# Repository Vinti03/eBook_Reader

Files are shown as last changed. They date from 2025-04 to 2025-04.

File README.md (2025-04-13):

# OpenBook E-Book Reader
Made by: Vintilescu Andrei-Florin, 332CA

University: UNSTPB, Bucharest

## Conținutul Repository-ului

OpenBook

    Hardware

        OpenBook.sch            // Fișierul schematic

        OpenBook.brd            // Fișierul PCB

    Manufacturing

        gerbers.zip             // Pachetul Gerber generat

        OpenBook.bom            // Bill Of Materials (BOM)

        OpenBook.cpl            // Fișier Pick and Place

    Mechanical

        OpenBook_exploded.step  // Model 3D exploded view (PCB + baterie + display + carcasă)

        OpenBook_Fusion360.f3d  // Fișierul 3D nativ Fusion360

    Images

        pcb_render.png          // Imagine cu randări ale PCB-ului

        device_render.png       // Randări ale dispozitivului complet

    LICENSE                     // Licența open source (ex. Apache 2.0)

    README.md                   // Acest fișier

## Diagramă Bloc a Sistemului
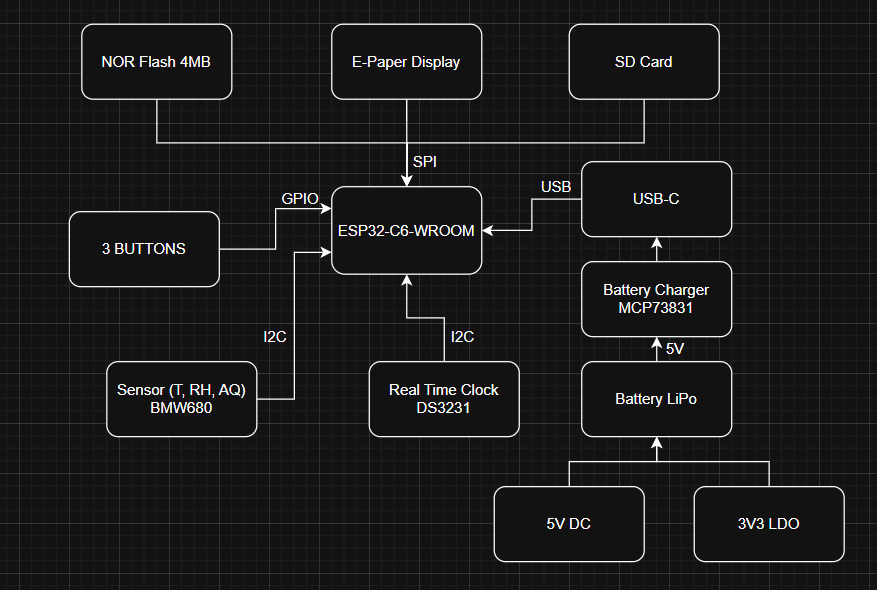
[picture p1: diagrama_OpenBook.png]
Diagrama bloc a proiectului OpenBook


## Bill Of Materials (BOM)

| Device | DATASHEET | PURCHASE-URL |
|---|---|---|
| ADAFRUIT_LEDCHIP-LED0603 | https://www.snapeda.com/parts/KP-1608SURCK/Kingbright/datasheet/ | https://www.snapeda.com/parts/KP-1608SURCK/Kingbright/view-part/?ref=search&t=LED%200603 |
| ESP32_WROVER_EAGLE-LTSPICE_RR0402 | https://analytics.supplyframe.com/trackingservlet/track/?r=0x34... (link lung) | https://componentsearchengine.com/part-view/R0402%201%25%20100%20K%20(RC0402FR-07100KL)/YAGEO |
| SJ | https://grabcad.com/library/solder-jumpers-1 | https://grabcad.com/library/solder-jumpers-1 |
| EAGLE-LTSPICE_CC0402 | https://analytics.supplyframe.com/trackingservlet/track/?r=0x34... (link lung) | https://componentsearchengine.com/part-view/CC0402MRX5R5BB106/YAGEO |
| ESP32_WROVER_EAGLE-LTSPICE_RR0402 | https://analytics.supplyframe.com/trackingservlet/track/?r=0x34... (link lung) | https://componentsearchengine.com/part-view/R0402%201%25%20100%20K%20(RC0402FR-07100KL)/YAGEO |
| ESP32_WROVER_EAGLE-LTSPICE_RR0402 | https://analytics.supplyframe.com/trackingservlet/track/?r=0x34... (link lung) | https://componentsearchengine.com/part-view/R0402%201%25%20100%20K%20(RC0402FR-07100KL)/YAGEO |
| EAGLE-LTSPICE_CC0402 | https://analytics.supplyframe.com/trackingservlet/track/?r=0x34... (link lung) | https://componentsearchengine.com/part-view/CC0402MRX5R5BB106/YAGEO |
| RCL_CPOL-EUCT3528 | https://s3.amazonaws.com/snapeda/datasheet/TAJB475K025RNJ_AVX.pdf | https://www.snapeda.com/parts/TAJB475K025RNJ/AVX/view-part/?ref=dk&t=capacitor%203528&con_ref=None |
| ESP32_WROVER_EAGLE-LTSPICE_RR0402 | https://analytics.supplyframe.com/trackingservlet/track/?r=0x34... (link lung) | https://componentsearchengine.com/part-view/R0402%201%25%20100%20K%20(RC0402FR-07100KL)/YAGEO |
| ESP32_WROVER_EAGLE-LTSPICE_RR0402 | https://analytics.supplyframe.com/trackingservlet/track/?r=0x34... (link lung) | https://componentsearchengine.com/part-view/R0402%201%25%20100%20K%20(RC0402FR-07100KL)/YAGEO |
| EAGLE-LTSPICE_CC0402 | https://analytics.supplyframe.com/trackingservlet/track/?r=0x34... (link lung) | https://componentsearchengine.com/part-view/CC0402MRX5R5BB106/YAGEO |
| 112A-TAAR-R03_ATTEND | https://store.comet.srl.ro/Catalogue/Product/43497/ | https://store.comet.srl.ro/Catalogue/Product/43497/ |
| ESP32_WROVER_EAGLE-LTSPICE_RR0402 | https://analytics.supplyframe.com/trackingservlet/track/?r=0x34... (link lung) | https://componentsearchengine.com/part-view/R0402%201%25%20100%20K%20(RC0402FR-07100KL)/YAGEO |
| EAGLE-LTSPICE_CC0402 | https://analytics.supplyframe.com/trackingservlet/track/?r=0x34... (link lung) | https://componentsearchengine.com/part-view/CC0402MRX5R5BB106/YAGEO |
| EAGLE-LTSPICE_CC0402 | https://analytics.supplyframe.com/trackingservlet/track/?r=0x34... (link lung) | https://componentsearchengine.com/part-view/CC0402MRX5R5BB106/YAGEO |
| ESP32_WROVER_EAGLE-LTSPICE_RR0402 | https://analytics.supplyframe.com/trackingservlet/track/?r=0x34... (link lung) | https://componentsearchengine.com/part-view/R0402%201%25%20100%20K%20(RC0402FR-07100KL)/YAGEO |
| ESP32_WROVER_EAGLE-LTSPICE_RR0402 | https://analytics.supplyframe.com/trackingservlet/track/?r=0x34... (link lung) | https://componentsearchengine.com/part-view/R0402%201%25%20100%20K%20(RC0402FR-07100KL)/YAGEO |
| ESP32_WROVER_SPARKFUN-DISCRETESEMI_MOSFET_PCH-DMG2305UX-7 | https://analytics.supplyframe.com/trackingservlet/track/?r=0x34... (link lung) | https://componentsearchengine.com/part-view/DMG2305UX-7/Diodes%20Incorporated |
| ESP32_WROVER_EAGLE-LTSPICE_RR0402 | https://analytics.supplyframe.com/trackingservlet/track/?r=0x34... (link lung) | https://componentsearchengine.com/part-view/R0402%201%25%20100%20K%20(RC0402FR-07100KL)/YAGEO |
| EAGLE-LTSPICE_CC0402 | https://analytics.supplyframe.com/trackingservlet/track/?r=0x34... (link lung) | https://componentsearchengine.com/part-view/CC0402MRX5R5BB106/YAGEO |
| EAGLE-LTSPICE_CC0402 | https://analytics.supplyframe.com/trackingservlet/track/?r=0x34... (link lung) | https://componentsearchengine.com/part-view/CC0402MRX5R5BB106/YAGEO |
| ESP32_WROVER_EAGLE-LTSPICE_RR0402 | https://analytics.supplyframe.com/trackingservlet/track/?r=0x34... (link lung) | https://componentsearchengine.com/part-view/R0402%201%25%20100%20K%20(RC0402FR-07100KL)/YAGEO |
| 744043680IND_4828-WE-TPC_WRE | https://www.we-online.com/components/products/datasheet/744043680.pdf | https://eu.mouser.com/ProductDetail/Wurth-Elektronik/744043680?qs=PGXP4M47uW6VkZq%252BkzjrHA%3D%3D |
| BD5229G-TR | https://analytics.supplyframe.com/trackingservlet/track/?r=0x34... (link lung) | https://componentsearchengine.com/part-view/XC6220A331MR-G/Torex |
| ESP32_WROVER_BME680_BME680 | https://www.snapeda.com/parts/BME680/Bosch%20Sensortec/datasheet/ | https://www.google.com/url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... |
| BUTTON_CUSYOMV1 | https://industry.panasonic.com/global/en/downloads?tab=catalog&small_g_cd=203&part_no=EVQPUJ02K | https://industry.panasonic.com/global/en/products/control/switch/light-touch/number/evqpuj02k |
| CPH3225A | https://www.snapeda.com/parts/CPH3225A/Seiko%20Instruments/datasheet/ | https://www.snapeda.com/parts/CPH3225A/Seiko+Instruments/view-part/?ref=eda |
| DS3231SN# | https://www.snapeda.com/parts/DS3231SN%23/Analog%20Devices/datasheet/ | https://www.snapeda.com/parts/DS3231SN%23/Analog+Devices/view-part/?ref=eda |
| ESP32-C6-WROOM-1-N8 | https://www.snapeda.com/parts/ESP32-C6-WROOM-1-N8/Espressif%20Systems/datasheet/ | https://www.snapeda.com/parts/ESP32-C6-WROOM-1-N8/Espressif+Systems/view-part/?ref=eda |
| ESP32C6_VARISTORCN1812 | https://www.snapeda.com/parts/MOV-10D561K/Bourns/datasheet/ | https://www.snapeda.com/parts/MOV-10D561K/Bourns/view-part/?welcome=home&ref=search&t=varistor |
| ESP32_WROVER_AVX---SD0805S020S1R0_AVX_SD0805S020S1R0_0_0AVX_SD0805S020S1R0_0_0 | https://ro.mouser.com/datasheet/2/40/schottky-3165252.pdf | https://ro.mouser.com/ProductDetail/KYOCERA-AVX/SD0805S020S1R0?qs=jCA%252BPfw4LHbpkAoSnwrdjw%3D%3D |
| ESP32_WROVER_SPARKFUN-IC-POWER_MCP73831 | https://eu.mouser.com/datasheet/2/268/MCP73831_Family_Data_Sheet_DS20001984H-3441711.pdf | https://eu.mouser.com/ProductDetail/Microchip-Technology/MCP73831T-2ACI-OT?qs=yUQqVecv4qvbBQBGbHx0Mw%3D%3D |
| FH34SRJ-24S-0.5SH_99_ | https://analytics.supplyframe.com/trackingservlet/track/?r=0x34... (link lung) | https://componentsearchengine.com/part-view/FH34SRJ-24S-0.5SH(99)/Hirose |
| MAX17048G+T10 | https://www.snapeda.com/parts/MAX17048G+T10/Analog%20Devices/datasheet/ | https://www.snapeda.com/parts/MAX17048G+T10/Analog+Devices/view-part/?ref=eda |
| MBR0530 | https://www.snapeda.com/parts/MBR0530/ON%20Semiconductor/datasheet/ | https://www.snapeda.com/parts/MBR0530/Onsemi/view-part/?ref=eda |
| PGB1010603MR | https://www.snapeda.com/parts/PGB1010603MR/Littelfuse%20Inc./datasheet/ | https://www.snapeda.com/parts/PGB1010603MR/Littelfuse/view-part/?ref=eda |
| QWIIC_RIGHT_ANGLE | https://eu.mouser.com/ProductDetail/Adafruit/4208?qs=PzGy0jfpSMtbScLbr0L5dw%3D%3D | https://eu.mouser.com/ProductDetail/Adafruit/4208?qs=PzGy0jfpSMtbScLbr0L5dw%3D%3D |
| SAMACSYS_PARTS_USB4110-GF-A | https://analytics.supplyframe.com/trackingservlet/track/?r=0x34... (link lung) | https://componentsearchengine.com/part-view/USB4110-GF-A/GCT%20(GLOBAL%20CONNECTOR%20TECHNOLOGY) |
| ESP32_WROVER_AVX---SD0805S020S1R0_AVX_SD0805S020S1R0_0_0AVX_SD0805S020S1R0_0_0 | https://ro.mouser.com/datasheet/2/40/schottky-3165252.pdf | https://ro.mouser.com/ProductDetail/KYOCERA-AVX/SD0805S020S1R0?qs=jCA%252BPfw4LHbpkAoSnwrdjw%3D%3D |
| SI1308EDL-T1-GE3 | https://www.snapeda.com/parts/SI1308EDL-T1-GE3/Vishay%20Siliconix/datasheet/ | https://www.snapeda.com/parts/SI1308EDL-T1-GE3/Vishay+Siliconix/view-part/?ref=eda |
| TPTP20R | self made | self made |
| USBLC6-2SC6Y | https://www.snapeda.com/parts/USBLC6-2SC6Y/STMicroelectronics/datasheet/ | https://www.snapeda.com/parts/USBLC6-2SC6Y/STMicroelectronics/view-part/?ref=eda |
| W25Q512JVEIQ | https://www.snapeda.com/parts/W25Q512JVEIQ/Winbond%20Electronics/datasheet/ | https://www.snapeda.com/parts/W25Q512JVEIQ/Winbond+Electronics/view-part/?ref=eda |
| XC6220A331MR-G | https://analytics.supplyframe.com/trackingservlet/track/?r=0x34... (link lung) | |

*Notă:* De asemenea lista completa de componente cu linkurile complete pentru datasheet si purchase-url o gasiti consultand fișierul `BOM.csv` inclus în directorul Manufacturing.

---

## Funcționalitatea Hardware în Detaliu

Acest proiect integrează următoarele module și componente:

- **ESP32-C6 Microcontroller:**  
  - Rol: Procesare centrală și interfațare cu toate componentele.  
  - Interfețe:  
    - UART pentru comunicare cu modulul e-Paper  
    - SPI pentru senzorii periferici  
    - I2C pentru conectarea accelerometrului și a altor senzori  
  - Specificații: Calcul estimativ de consum energetic, rutare optimizată a pinilor și implementare a planurilor de masă pe ambele straturi (TOP și BOTTOM) pentru stabilitate electrică.

- **Display e-Paper:**  
  - Rol: Afișare de text și imagini cu consum redus de energie.  
  - Interfață: SPI, cu un set dedicat de pini conectați direct la ESP32-C6.
  
- **Baterie LiPo:**  
  - Rol: Alimentarea dispozitivului.  
  - Observații: Bateria este conectată direct la patru test pad-uri conform specificațiilor pentru economisirea spațiului.  
 
- **Decuplaje și Protecții:**  
  - Utilizare condensatoare 100 nF amplasate cât mai aproape de pinii de alimentare pentru a asigura o decuplare corespunzătoare.  
  - Rutare a traseelor de putere la 0.3mm, iar semnalele de date la cel puțin 0.15mm conform specificațiilor.

- **Plan de Masă și Rutare:**  
  - Implementare a unui plan de masă atât pe layer-ul TOP cât și pe BOTTOM.  
  - Vias-urile au fost plasate strategic și folosim tehnici de Via Stitching, în special în zona modulului ESP32, pentru a minimiza interferențele.

- **Constrângeri Mecanice:**  
  - PCB-ul de 1mm grosime este proiectat să se încadreze perfect în carcasa specificată.  
  - Toate componentele principale sunt grupate în jurul microcontroller-ului și amplasate exclusiv pe layer-ul TOP de conformitate cu cerințele proiectului.

---

## Configurarea și Utilizarea Pinii ESP32-C6

Mai jos este un sumar al pinilor utilizați și a motivelor alese:

| Pin ESP32-C6 | Funcționalitate Asociată | Motiv/Observații |
|---|---|---|
| GPIO12 | SPI_MISO pentru Display e-Paper  | Necesită viteză mare și stabilitate la semnal  |
| GPIO13 | SPI_MOSI pentru Display e-Paper  | Pentru comunicații rapide și fiabile |
| GPIO14 | SPI_CLK pentru Display e-Paper | Sincronizare precisă a semnalului |
| GPIO15 | CS (Chip Select) pentru e-Paper  | Control dedicated pentru selecție modul |
| GPIO2 | I2C SDA pentru Senzori | Interfață I2C standard pentru accelerometru/senzori |
| GPIO4 | I2C SCL pentru Senzori | Necesită semnal clar pentru sincronizarea I2C  |
| ... | Alte pini alocați conform necesităților proiectului | Consultare schema detaliată pentru alocare |

## Concluzie

  Proiectul OpenBook a urmarit dezvoltarea unui dispozitiv e-book reader accesibil, open-source, cu un design hardware optimizat pentru productie de masa. Am parcurs toate etapele de validare, de la schema electrica si PCB pana la integrarea mecanica completa in carcasa finala. Design-ul respecta constrangerile functionale, mecanice si de buna practica, fiind pregatit pentru testare si productie. Documentatia completa si fisierele necesare sunt disponibile in acest repository.

---

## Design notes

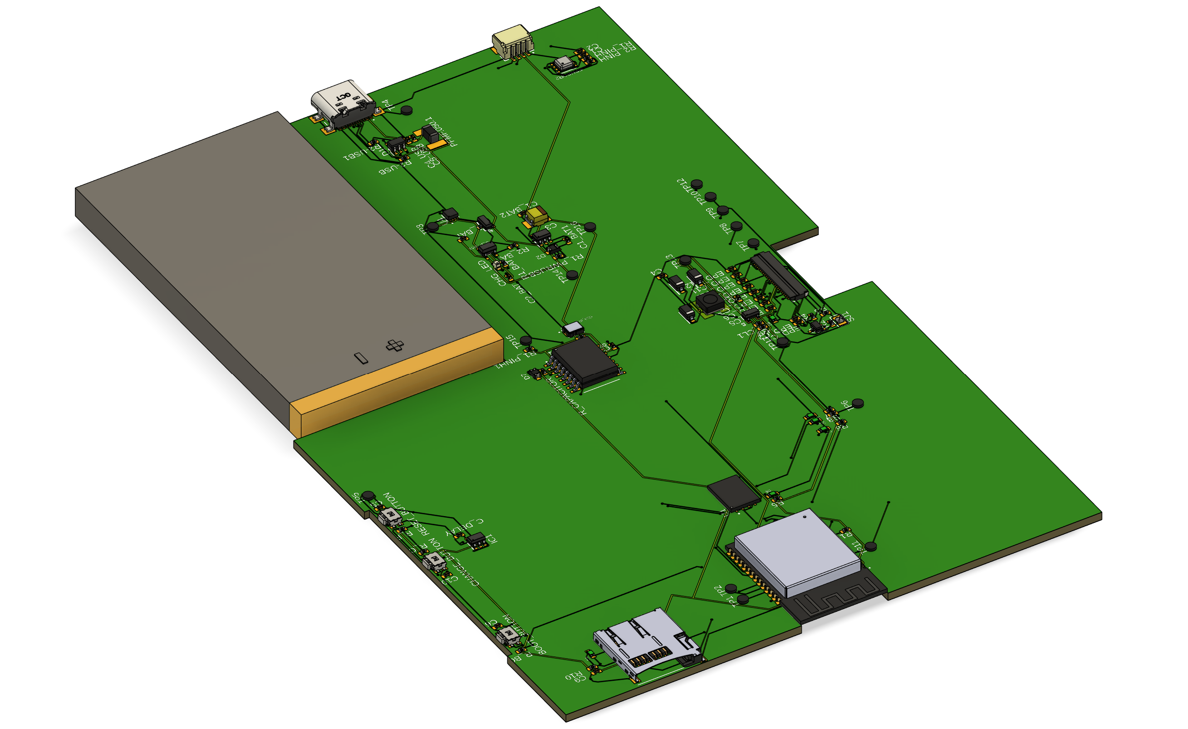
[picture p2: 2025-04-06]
Images/PCDB with Battery.png

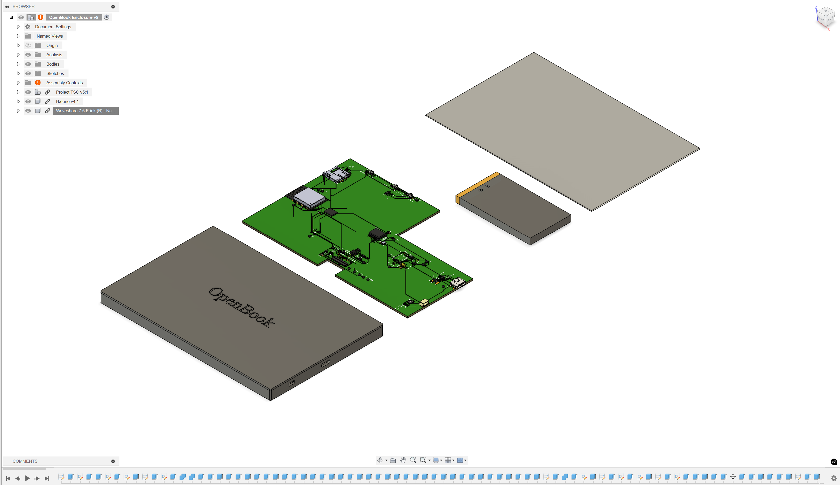
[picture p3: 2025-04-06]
Images/Exploded view.png

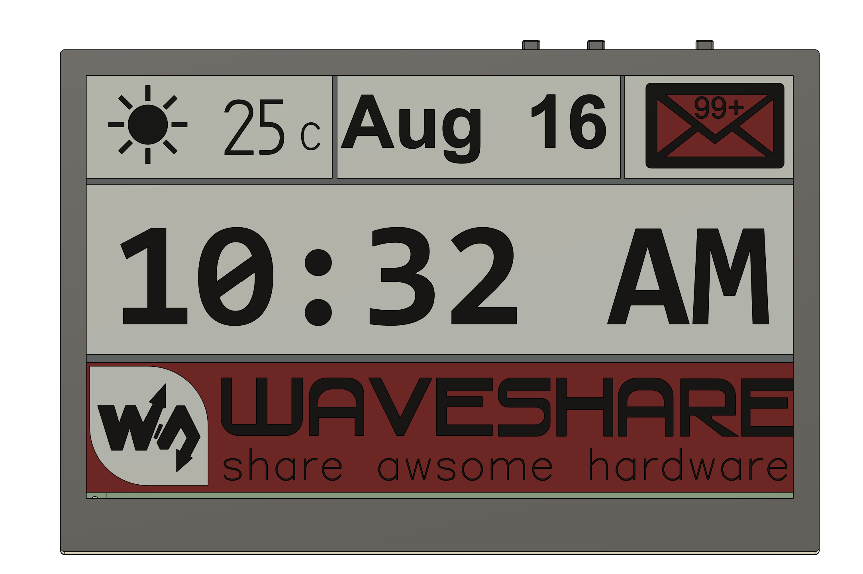
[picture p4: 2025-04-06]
Images/The final product.png

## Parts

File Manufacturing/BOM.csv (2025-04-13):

Qty | Value | Device | Package | Parts | Description | ARROW_PART_NUMBER | ARROW_PRICE-STOCK | AVAILABILITY | CENTROID_NOT_SPECIFIED | CHECK_PRICES | COPYRIGHT | DATASHEET | DESCRIPTION | DIGIKEY_DESCRIPTION | DIGIKEY_PART_NUMBER | HEIGHT | LEAD_FREE | MANUFACTURER_NAME | MANUFACTURER_PART_NUMBER | MF | MFR_NAME | MOUSER_PART_NUMBER | MOUSER_PRICE-STOCK | MOUSER_TESTING_PART_NUMBER | MOUSER_TESTING_PRICE-STOCK | MP | MPN | PACKAGE | POPULARITY | PREFIX | PRICE | PROD_ID | PURCHASE-URL | ROHS | SNAPEDA_LINK | SPICEMODEL | SPICEPREFIX | TEMPERATURE_RANGE_HIGH | TEMPERATURE_RANGE_LOW | TP_SIGNAL_NAME | VALUE
1 |  | ADAFRUIT_LEDCHIP-LED0603 | ADAFRUIT_CHIP-LED0603 | CHG_LED | LED |  |  |  |  |  | https://www.snapeda.com/parts/KP-1608SURCK/Kingbright/datasheet/ | https://www.snapeda.com/parts/KP-1608SURCK/Kingbright/datasheet/ |  |  |  |  |  |  |  |  |  |  |  |  |  |  |  |  |  |  |  |  | https://www.snapeda.com/parts/KP-1608SURCK/Kingbright/view-part/?ref=search&t=LED%200603
2 |  | ESP32_WROVER_EAGLE-LTSPICE_RR0402 | ESP32_WROVER_EAGLE-LTSPICE_R0402 | R1, R_CHANGE | RESISTOR, European symbol |  |  |  |  |  |  | https://analytics.supplyframe.com/trackingservlet/track/ |  |  |  |  |  |  |  |  |  |  |  |  |  |  |  |  |  |  |  |  | https://componentsearchengine.com/part-view/R0402%201%25%20100%20K%20(RC0402FR-07100KL)/YAGEO |  |  | NONE | R
1 |  | SJ | SJ | SJ1 | SMD solder JUMPER |  |  |  |  |  |  | https://grabcad.com/library/solder-jumpers-1 |  |  |  |  |  |  |  |  |  |  |  |  |  |  |  |  | 3 |  |  |  | https://grabcad.com/library/solder-jumpers-1
1 | 0.1uF/50V | EAGLE-LTSPICE_CC0402 | EAGLE-LTSPICE_C0402 | EPD_C5 | CAPACITOR, European symbol |  |  |  |  |  |  | https://analytics.supplyframe.com/trackingservlet/track/ |  |  |  |  |  |  |  |  |  |  |  |  |  |  |  |  |  |  |  |  | https://componentsearchengine.com/part-view/CC0402MRX5R5BB106/YAGEO |  |  | NONE | C
1 | 0.47 | ESP32_WROVER_EAGLE-LTSPICE_RR0402 | ESP32_WROVER_EAGLE-LTSPICE_R0402 | R3 | RESISTOR, European symbol |  |  |  |  |  |  | https://analytics.supplyframe.com/trackingservlet/track/ |  |  |  |  |  |  |  |  |  |  |  |  |  |  |  |  |  |  |  |  | https://componentsearchengine.com/part-view/R0402%201%25%20100%20K%20(RC0402FR-07100KL)/YAGEO |  |  | NONE | R
1 | 100k | ESP32_WROVER_EAGLE-LTSPICE_RR0402 | ESP32_WROVER_EAGLE-LTSPICE_R0402 | R1_PWRUSB | RESISTOR, European symbol |  |  |  |  |  |  | https://analytics.supplyframe.com/trackingservlet/track/ |  |  |  |  |  |  |  |  |  |  |  |  |  |  |  |  |  |  |  |  | https://componentsearchengine.com/part-view/R0402%201%25%20100%20K%20(RC0402FR-07100KL)/YAGEO |  |  | NONE | R
8 | 100nF | EAGLE-LTSPICE_CC0402 | EAGLE-LTSPICE_C0402 | C1, C2, C4_USB, C6, C8, C9, C10, C_DELAY | CAPACITOR, European symbol |  |  |  |  |  |  | https://analytics.supplyframe.com/trackingservlet/track/ |  |  |  |  |  |  |  |  |  |  |  |  |  |  |  |  |  |  |  |  | https://componentsearchengine.com/part-view/CC0402MRX5R5BB106/YAGEO |  |  | NONE | C
1 | 100uF TANT | RCL_CPOL-EUCT3528 | RCL_CT3528 | C3 | POLARIZED CAPACITOR, European symbol |  |  |  |  |  |  | https://s3.amazonaws.com/snapeda/datasheet/TAJB475K025RNJ_AVX.pdf |  |  |  |  |  |  |  |  |  |  |  |  |  |  |  |  | 0 |  |  |  | https://www.snapeda.com/parts/TAJB475K025RNJ/AVX/view-part/?ref=dk&t=capacitor%203528&con_ref=None |  |  |  | C
13 | 10K | ESP32_WROVER_EAGLE-LTSPICE_RR0402 | ESP32_WROVER_EAGLE-LTSPICE_R0402 | R1_PINH, R1_PINH1, R2-PINH1, R2_PINH, R5, R6, R7, R8, R9, R10, R_BOOT, R_CL1, R_RESET | RESISTOR, European symbol |  |  |  |  |  |  | https://analytics.supplyframe.com/trackingservlet/track/ |  |  |  |  |  |  |  |  |  |  |  |  |  |  |  |  |  |  |  |  | https://componentsearchengine.com/part-view/R0402%201%25%20100%20K%20(RC0402FR-07100KL)/YAGEO |  |  | NONE | R
1 | 10k | ESP32_WROVER_EAGLE-LTSPICE_RR0402 | ESP32_WROVER_EAGLE-LTSPICE_R0402 | R4 | RESISTOR, European symbol |  |  |  |  |  |  | https://analytics.supplyframe.com/trackingservlet/track/ |  |  |  |  |  |  |  |  |  |  |  |  |  |  |  |  |  |  |  |  | https://componentsearchengine.com/part-view/R0402%201%25%20100%20K%20(RC0402FR-07100KL)/YAGEO |  |  | NONE | R
1 | 10uF | EAGLE-LTSPICE_CC0402 | EAGLE-LTSPICE_C0402 | C7 | CAPACITOR, European symbol |  |  |  |  |  |  | https://analytics.supplyframe.com/trackingservlet/track/ |  |  |  |  |  |  |  |  |  |  |  |  |  |  |  |  |  |  |  |  | https://componentsearchengine.com/part-view/CC0402MRX5R5BB106/YAGEO |  |  | NONE | C
1 | 112A-TAAR-R03_ATTEND | 112A-TAAR-R03_ATTEND | 112ATAARR03ATTEND | J4 | Micro SD Card Socket, Push-Push Type, Top Mount, SMT, H=1.83mm, 10u |  |  |  |  |  |  | https://store.comet.srl.ro/Catalogue/Product/43497/ | Micro SD Card Socket | Push-Push Type | Top Mount | SMT | H=1.83mm | 10u |  |  | 1.9mm |  | ATTEND | 112A-TAAR-R03 ATTEND |  |  |  |  |  |  |  |  | https://store.comet.srl.ro/Catalogue/Product/43497/
1 | 15 | ESP32_WROVER_EAGLE-LTSPICE_RR0402 | ESP32_WROVER_EAGLE-LTSPICE_R0402 | R_CAPACITOR | RESISTOR, European symbol |  |  |  |  |  |  | https://analytics.supplyframe.com/trackingservlet/track/ |  |  |  |  |  |  |  |  |  |  |  |  |  |  |  |  |  |  |  |  | https://componentsearchengine.com/part-view/R0402%201%25%20100%20K%20(RC0402FR-07100KL)/YAGEO |  |  | NONE | R
1 | 1uF | EAGLE-LTSPICE_CC0402 | EAGLE-LTSPICE_C0402 | C5 | CAPACITOR, European symbol |  |  |  |  |  |  | https://analytics.supplyframe.com/trackingservlet/track/ |  |  |  |  |  |  |  |  |  |  |  |  |  |  |  |  |  |  |  |  | https://componentsearchengine.com/part-view/CC0402MRX5R5BB106/YAGEO |  |  | NONE | C
9 | 1uF/50V | EAGLE-LTSPICE_CC0402 | EAGLE-LTSPICE_C0402 | EPD_C1, EPD_C2, EPD_C6, EPD_C7, EPD_C8, EPD_C9, EPD_C10, EPD_C11, EPD_C12 | CAPACITOR, European symbol |  |  |  |  |  |  | https://analytics.supplyframe.com/trackingservlet/track/ |  |  |  |  |  |  |  |  |  |  |  |  |  |  |  |  |  |  |  |  | https://componentsearchengine.com/part-view/CC0402MRX5R5BB106/YAGEO |  |  | NONE | C
1 | 2.2 | ESP32_WROVER_EAGLE-LTSPICE_RR0402 | ESP32_WROVER_EAGLE-LTSPICE_R0402 | R2 | RESISTOR, European symbol |  |  |  |  |  |  | https://analytics.supplyframe.com/trackingservlet/track/ |  |  |  |  |  |  |  |  |  |  |  |  |  |  |  |  |  |  |  |  | https://componentsearchengine.com/part-view/R0402%201%25%20100%20K%20(RC0402FR-07100KL)/YAGEO |  |  | NONE | R
1 | 200 | ESP32_WROVER_EAGLE-LTSPICE_RR0402 | ESP32_WROVER_EAGLE-LTSPICE_R0402 | R1_BAT | RESISTOR, European symbol |  |  |  |  |  |  | https://analytics.supplyframe.com/trackingservlet/track/ |  |  |  |  |  |  |  |  |  |  |  |  |  |  |  |  |  |  |  |  | https://componentsearchengine.com/part-view/R0402%201%25%20100%20K%20(RC0402FR-07100KL)/YAGEO |  |  | NONE | R
2 | 20V/4.2A/52mO/1.4W | ESP32_WROVER_SPARKFUN-DISCRETESEMI_MOSFET_PCH-DMG2305UX-7 | ESP32_WROVER_SPARKFUN-DISCRETESEMI_SOT23-3 | Q1, Q2 | P-channel MOSFETs |  |  |  |  |  |  | https://analytics.supplyframe.com/trackingservlet/track/ |  |  |  |  |  |  |  |  |  |  |  |  |  |  |  |  |  |  |  | TRAN-14388 | https://componentsearchengine.com/part-view/DMG2305UX-7/Diodes%20Incorporated |  |  |  |  |  |  |  | 20V/4.2A/52mO/1.4W
1 | 2K | ESP32_WROVER_EAGLE-LTSPICE_RR0402 | ESP32_WROVER_EAGLE-LTSPICE_R0402 | R2_BAT | RESISTOR, European symbol |  |  |  |  |  |  | https://analytics.supplyframe.com/trackingservlet/track/ |  |  |  |  |  |  |  |  |  |  |  |  |  |  |  |  |  |  |  |  | https://componentsearchengine.com/part-view/R0402%201%25%20100%20K%20(RC0402FR-07100KL)/YAGEO |  |  | NONE | R
5 | 4.7uF | EAGLE-LTSPICE_CC0402 | EAGLE-LTSPICE_C0402 | C1_BAT, C1_BAT1, C1_BAT2, C2_BAT, C5_USB | CAPACITOR, European symbol |  |  |  |  |  |  | https://analytics.supplyframe.com/trackingservlet/track/ |  |  |  |  |  |  |  |  |  |  |  |  |  |  |  |  |  |  |  |  | https://componentsearchengine.com/part-view/CC0402MRX5R5BB106/YAGEO |  |  | NONE | C
1 | 4.7uF/25V | EAGLE-LTSPICE_CC0402 | EAGLE-LTSPICE_C0402 | C4 | CAPACITOR, European symbol |  |  |  |  |  |  | https://analytics.supplyframe.com/trackingservlet/track/ |  |  |  |  |  |  |  |  |  |  |  |  |  |  |  |  |  |  |  |  | https://componentsearchengine.com/part-view/CC0402MRX5R5BB106/YAGEO |  |  | NONE | C
2 | 5k1 | ESP32_WROVER_EAGLE-LTSPICE_RR0402 | ESP32_WROVER_EAGLE-LTSPICE_R0402 | R2-USB, R2-USB1 | RESISTOR, European symbol |  |  |  |  |  |  | https://analytics.supplyframe.com/trackingservlet/track/ |  |  |  |  |  |  |  |  |  |  |  |  |  |  |  |  |  |  |  |  | https://componentsearchengine.com/part-view/R0402%201%25%20100%20K%20(RC0402FR-07100KL)/YAGEO |  |  | NONE | R
1 | 68uH | 744043680IND_4828-WE-TPC_WRE | IND_4828-WE-TPC_WRE | L1 |  |  |  |  |  |  | Copyright (C) 2024 Ultra Librarian. All rights reserved. | https://www.we-online.com/components/products/datasheet/744043680.pdf |  |  |  |  |  |  | 744043680 |  | Wurth Electronics |  |  |  |  |  |  |  |  |  |  |  | https://eu.mouser.com/ProductDetail/Wurth-Elektronik/744043680?qs=PGXP4M47uW6VkZq%252BkzjrHA%3D%3D
1 | BD5229G-TR | BD5229G-TR | SOT95P280X120-5N | IC1 | Voltage Detector with Adjustable Delay Time: CMOS processes are utilized to develop high precision, low current consumption CMOS reset ICs that allow arbitrary setting of the delay time. The extensive lineup includes both Nch Open Drain and CMOS output types in a wide range of detection voltages (from 2.3V to 6.0V, in 0.1V steps), enabling selection of the ideal solution based on customer requirements. In addition, the entire series is of course both lead-free and RoHS-compliant. |  |  |  |  |  |  | https://analytics.supplyframe.com/trackingservlet/track/ | Voltage Detector with Adjustable Delay Time: CMOS processes are utilized to develop high precision | low current consumption CMOS reset ICs that allow arbitrary setting of the delay time. The extensive lineup includes both Nch Open Drain and CMOS output types in a wide range of detection voltages (from 2.3V to 6.0V | in 0.1V steps) | enabling selection of the ideal solution based on customer requirements. In addition | the entire series is of course both lead-free and RoHS-compliant. |  |  | 1.25mm |  | ROHM Semiconductor | BD5229G-TR |  |  | 755-BD5229G-TR | https://www.mouser.co.uk/ProductDetail/ROHM-Semiconductor/BD5229G-TR?qs=4kLU8WoGk0vvnhrrYwdszw%3D%3D |  |  |  |  |  | https://componentsearchengine.com/part-view/XC6220A331MR-G/Torex
1 | BME688 | ESP32_WROVER_BME680_BME680 | ESP32_WROVER_BME680_PSON80P300X300X100-8N | SENSOR2 | Integrated Environmental Unit |  |  | Unavailable |  |  |  | https://www.snapeda.com/parts/BME680/Bosch%20Sensortec/datasheet/ | Integrated Environmental Unit |  |  |  |  |  |  | Bosch Sensortec |  |  |  |  |  | BME680 |  | LGA-8 Bosch Tools |  |  | None |  | https://www.snapeda.com/parts/BME680/Bosch/view-part/?welcome=home
3 | BUTTON_CUSYOMV1 | BUTTON_CUSYOMV1 | MYBUTTON | BOOT_BUTTON, CHANGE_BUTTON, RESET_BUTTON |  |  |  |  |  |  |  | https://industry.panasonic.com/global/en/downloads?tab=catalog&small_g_cd=203&part_no=EVQPUJ02K |  |  |  |  |  |  |  |  |  |  |  |  |  |  |  |  |  |  |  |  | https://industry.panasonic.com/global/en/products/control/switch/light-touch/number/evqpuj02k
1 | CPH3225A | CPH3225A | CAPCP3225X100N | C10_SUPERCAP | Cap 0.011F 3.3V 1210 Flat Check availability |  |  | Not in stock |  | https://www.snapeda.com/parts/CPH3225A/Seiko+Instruments/view-part/?ref=eda |  | https://www.snapeda.com/parts/CPH3225A/Seiko%20Instruments/datasheet/ | 11 mF (EDLC) Supercapacitor 3.3 V 1210 (3225 Metric) - - |  |  |  |  |  |  | Seiko Instruments |  |  |  |  |  | CPH3225A |  | 1210 Seiko |  |  | None |  | https://www.snapeda.com/parts/CPH3225A/Seiko+Instruments/view-part/?ref=eda |  | https://www.snapeda.com/parts/CPH3225A/Seiko+Instruments/view-part/?ref=snap
1 | DS3231SN# | DS3231SN# | SOIC127P1032X265-16N | U3 | Real Time Clock Serial 16-Pin SOIC W T/R Check availability |  |  | In Stock |  | https://www.snapeda.com/parts/DS3231SN%23/Analog+Devices/view-part/?ref=eda |  | https://www.snapeda.com/parts/DS3231SN%23/Analog%20Devices/datasheet/ | Extremely Accurate I涎-Integrated RTC/TCXO/Crystal |  |  |  |  |  |  | Analog Devices |  |  |  |  |  | DS3231SN# |  | SOIC-16 Maxim |  |  | None |  | https://www.snapeda.com/parts/DS3231SN%23/Analog+Devices/view-part/?ref=eda |  | https://www.snapeda.com/parts/DS3231SN%23/Analog+Devices/view-part/?ref=snap
1 | ESP32-C6-WROOM-1-N8 | ESP32-C6-WROOM-1-N8 | XCVR_ESP32-C6-WROOM-1-N8 | U2 | Check availability |  |  | In Stock |  | https://www.snapeda.com/parts/ESP32-C6-WROOM-1-N8/Espressif+Systems/view-part/?ref=eda |  | https://www.snapeda.com/parts/ESP32-C6-WROOM-1-N8/Espressif%20Systems/datasheet/ | Multiprotocol Modules ESP32-C6 module | Wi-Fi 6 in 2.4 GHz band | Bluetooth 5 | Zigbee 3.0 and Thread. ESP34-WROOM Compatible - ENGINEERING SAMPLE |  |  |  |  |  |  | Espressif Systems |  |  |  |  |  | ESP32-C6-WROOM-1-N8 |  | None |  | https://www.snapeda.com/parts/ESP32-C6-WROOM-1-N8/Espressif+Systems/view-part/?ref=eda | None |  |  |  | https://www.snapeda.com/parts/ESP32-C6-WROOM-1-N8/Espressif+Systems/view-part/?ref=snap
1 | ESP32C6_VARISTORCN1812 | ESP32C6_VARISTORCN1812 | ESP32C6_VARISTOR_CT/CN1812 | PFMF.050.1 | VARISTOR |  |  |  |  |  |  | https://www.snapeda.com/parts/MOV-10D561K/Bourns/datasheet/ |  |  |  |  |  |  |  |  |  |  |  |  |  |  |  |  | 0 |  |  |  | https://www.snapeda.com/parts/MOV-10D561K/Bourns/view-part/?welcome=home&ref=search&t=varistor
1 | ESP32_WROVER_AVX---SD0805S020S1R0_AVX_SD0805S020S1R0_0_0AVX_SD0805S020S1R0_0_0 | ESP32_WROVER_AVX---SD0805S020S1R0_AVX_SD0805S020S1R0_0_0AVX_SD0805S020S1R0_0_0 | ESP32_WROVER_AVX---SD0805S020S1R0_AVX_SD0805S020S1R0_0 | D7 | Schottky Barrier Rectifier Diode |  |  |  | No |  |  | https://ro.mouser.com/datasheet/2/40/schottky-3165252.pdf |  | DIODE SCHOTTKY 20V 1A 0805 | 478-7800-1-ND |  | yes |  |  | AVX |  | 581-SD0805S020S1R0 |  |  |  |  |  | 0805 (2012 metric) |  | D |  |  | https://ro.mouser.com/ProductDetail/KYOCERA-AVX/SD0805S020S1R0?qs=jCA%252BPfw4LHbpkAoSnwrdjw%3D%3D | yes |  |  |  | +125蚓 | -55蚓
1 | ESP32_WROVER_SPARKFUN-IC-POWER_MCP73831 | ESP32_WROVER_SPARKFUN-IC-POWER_MCP73831 | ESP32_WROVER_SPARKFUN-IC-POWER_SOT23-5 | MCP73831 | MCP73831T Li-Ion, Li-Pol Controller |  |  |  |  |  |  | https://eu.mouser.com/datasheet/2/268/MCP73831_Family_Data_Sheet_DS20001984H-3441711.pdf |  |  |  |  |  |  |  |  |  |  |  |  |  |  |  |  |  |  |  | IC-09995 | https://eu.mouser.com/ProductDetail/Microchip-Technology/MCP73831T-2ACI-OT?qs=yUQqVecv4qvbBQBGbHx0Mw%3D%3D
1 | FH34SRJ-24S-0.5SH_99_ | FH34SRJ-24S-0.5SH_99_ | FH34SRJ24S05SH99 | J1 | (0.50mm) Surface Mount, Right Angle |  |  |  |  |  |  | https://analytics.supplyframe.com/trackingservlet/track/ | 24 Position FFC | FPC Connector Contacts | (0.50mm) Surface Mount | Right Angle |  |  | 1.1mm |  | Hirose | FH34SRJ-24S-0.5SH(99) |  |  | 798-FH34SRJ24S05SH99 | https://www.mouser.co.uk/ProductDetail/Hirose-Connector/FH34SRJ-24S-0.5SH99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 |  |  |  |  |  |  | https://componentsearchengine.com/part-view/FH34SRJ-24S-0.5SH(99)/Hirose
1 | MAX17048G+T10 | MAX17048G+T10 | SON50P200X200X80-9N | U4 | Check availability |  |  | In Stock |  | https://www.snapeda.com/parts/MAX17048G+T10/Analog+Devices/view-part/?ref=eda |  | https://www.snapeda.com/parts/MAX17048G+T10/Analog%20Devices/datasheet/ | 3渙 1-Cell/2-Cell Fuel Gauge with ModelGauge |  |  |  |  |  |  | Analog Devices |  |  |  |  |  | MAX17048G+T10 |  | TDFN-8 Maxim |  |  | None |  | https://www.snapeda.com/parts/MAX17048G+T10/Analog+Devices/view-part/?ref=eda |  | https://www.snapeda.com/parts/MAX17048G+T10/Analog+Devices/view-part/?ref=snap
3 | MBR0530 | MBR0530 | SOD3716X135N | D3, D4, D5 | ON SEMICONDUCTOR - MBR0530 - DIODE, SCHOTTKY, 0.5A, 30V, SOD-123 |  |  | In Stock |  | https://www.snapeda.com/parts/MBR0530/Onsemi/view-part/?ref=eda |  | https://www.snapeda.com/parts/MBR0530/ON%20Semiconductor/datasheet/ | Diode Schottky 30 V 500mA Surface Mount SOD-123 |  |  |  |  |  |  | ON Semiconductor |  |  |  |  |  | MBR0530 |  | SOD-123-2 ON Semiconductor |  |  | None |  | https://www.snapeda.com/parts/MBR0530/Onsemi/view-part/?ref=eda |  | https://www.snapeda.com/parts/MBR0530/Onsemi/view-part/?ref=snap
6 | PGB1010603MR | PGB1010603MR | DIOC1608X36N | D6, D8, D9, D10, D11, D12 | Check availability |  |  | In Stock |  | https://www.snapeda.com/parts/PGB1010603MR/Littelfuse/view-part/?ref=eda |  | https://www.snapeda.com/parts/PGB1010603MR/Littelfuse%20Inc./datasheet/ | 150V (Typ) Clamp - Ipp Tvs Diode Surface Mount 0603 (1608 Metric) |  |  |  |  |  |  | Littelfuse Inc. |  |  |  |  |  | PGB1010603MR |  | 0603 Littelfuse Inc. |  |  | None |  | https://www.snapeda.com/parts/PGB1010603MR/Littelfuse/view-part/?ref=eda |  | https://www.snapeda.com/parts/PGB1010603MR/Littelfuse/view-part/?ref=snap
1 | QWIIC_RIGHT_ANGLE | QWIIC_CONNECTORJS-1MM | JST04_1MM_RA | J3 | SparkFun I2C Standard Qwiic Connector |  |  |  |  |  |  | https://eu.mouser.com/ProductDetail/Adafruit/4208?qs=PzGy0jfpSMtbScLbr0L5dw%3D%3D |  |  |  |  |  |  |  |  |  |  |  |  |  |  |  |  |  |  |  | CONN-13694 | https://eu.mouser.com/ProductDetail/Adafruit/4208?qs=PzGy0jfpSMtbScLbr0L5dw%3D%3D |  |  |  |  |  |  |  | QWIIC_RIGHT_ANGLE
1 | SAMACSYS_PARTS_USB4110-GF-A | SAMACSYS_PARTS_USB4110-GF-A | SAMACSYS_PARTS_USB4110GFA | J2 | CONN USB 2.0 TYPE-C R/A SMT |  |  |  |  |  |  | https://analytics.supplyframe.com/trackingservlet/track/ | CONN USB 2.0 TYPE-C R/A SMT |  |  | 3.26mm |  | GCT (GLOBAL CONNECTOR TECHNOLOGY) | USB4110-GF-A |  |  | 640-USB4110-GF-A | https://www.mouser.co.uk/ProductDetail/GCT/USB4110-GF-A?qs=KUoIvG%2F9IlYiZvIXQjyJeA%3D%3D |  |  |  |  |  |  |  |  |  | https://componentsearchengine.com/part-view/USB4110-GF-A/GCT%20(GLOBAL%20CONNECTOR%20TECHNOLOGY)
1 | SD0805S020S1R0 | ESP32_WROVER_AVX---SD0805S020S1R0_AVX_SD0805S020S1R0_0_0AVX_SD0805S020S1R0_0_0 | ESP32_WROVER_AVX---SD0805S020S1R0_AVX_SD0805S020S1R0_0 | D2 | Schottky Barrier Rectifier Diode |  |  |  | No |  |  | https://ro.mouser.com/datasheet/2/40/schottky-3165252.pdf |  | DIODE SCHOTTKY 20V 1A 0805 | 478-7800-1-ND |  | yes |  |  | AVX |  | 581-SD0805S020S1R0 |  |  |  |  |  | 0805 (2012 metric) |  | D |  |  | https://ro.mouser.com/ProductDetail/KYOCERA-AVX/SD0805S020S1R0?qs=jCA%252BPfw4LHbpkAoSnwrdjw%3D%3D | yes |  |  |  | +125蚓 | -55蚓
1 | SI1308EDL-T1-GE3 | SI1308EDL-T1-GE3 | SOT65P210X110-3N | Q3 | MOSFET N-Ch 30V 1.5A TrenchFET SC70 Vishay Si1308EDL-T1-GE3 N-channel MOSFET Transistor, 1.5 A, 30 V, 3-Pin SC-70 |  |  | In Stock |  | https://www.snapeda.com/parts/SI1308EDL-T1-GE3/Vishay+Siliconix/view-part/?ref=eda |  | https://www.snapeda.com/parts/SI1308EDL-T1-GE3/Vishay%20Siliconix/datasheet/ | Si1308EDL-T1-GE3 N-channel MOSFET Transistor | 1.5 A | 30 V | 3-Pin SC-70 | Siliconix / Vishay SI1308EDL-T1-GE3 |  |  |  |  |  |  | Vishay Siliconix |  |  |  |  |  | SI1308EDL-T1-GE3 |  | SOT-323 Vishay Semiconductor |  | https://www.snapeda.com/parts/SI1308EDL-T1-GE3/Vishay+Siliconix/view-part/?ref=eda | None |  | https://www.snapeda.com/api/url_track_click_mouser/?unipart_id=274603&manufacturer=Vishay Siliconix&part_name=SI1308EDL-T1-GE3&search_term=None |  | https://www.snapeda.com/parts/SI1308EDL-T1-GE3/Vishay+Siliconix/view-part/?ref=snap
17 | TPTP20R | TPTP20R | TP20R | TP1, TP2, TP3, TP4, TP5, TP6, TP7, TP8, TP9, TP10, TP11, TP12, TP13, TP14, TP15, TP16, TP17 | Test pad |  |  |  |  |  |  | self made |  |  |  |  |  |  |  |  |  |  |  |  |  |  |  |  | 2 |  |  |  | self made
1 | USBLC6-2SC6Y | USBLC6-2SC6Y | SOT95P280X145-6N | D1 | Low Cap. ESD Protection Auto SOT-23-6 STMicroelectronics USBLC6-2SC6Y, Dual Uni-Directional TVS Diode Array, 6-Pin SOT-23 |  |  | In Stock |  | https://www.snapeda.com/parts/USBLC6-2SC6Y/STMicroelectronics/view-part/?ref=eda |  | https://www.snapeda.com/parts/USBLC6-2SC6Y/STMicroelectronics/datasheet/ | 17V Clamp 5A (8/20盜) Ipp Tvs Diode Surface Mount SOT-23-6 |  |  |  |  |  |  | STMicroelectronics |  |  |  |  |  | USBLC6-2SC6Y |  | SOT-23-6 STMicroelectronics |  |  | None |  | https://www.snapeda.com/parts/USBLC6-2SC6Y/STMicroelectronics/view-part/?ref=eda |  | https://www.snapeda.com/parts/USBLC6-2SC6Y/STMicroelectronics/view-part/?ref=snap
1 | W25Q512JVEIQ | W25Q512JVEIQ | SON127P600X800X80-9N | U1 | Check availability |  |  | In Stock |  | https://www.snapeda.com/parts/W25Q512JVEIQ/Winbond+Electronics/view-part/?ref=eda |  | https://www.snapeda.com/parts/W25Q512JVEIQ/Winbond%20Electronics/datasheet/ | FLASH - NOR Memory IC 512Mb (64M x 8) SPI - Quad I/O 133 MHz 8-WSON (8x6) |  |  |  |  |  |  | Winbond Electronics |  |  |  |  |  | W25Q512JVEIQ |  | Package |  |  | None |  | https://www.snapeda.com/parts/W25Q512JVEIQ/Winbond+Electronics/view-part/?ref=eda |  | https://www.snapeda.com/parts/W25Q512JVEIQ/Winbond+Electronics/view-part/?ref=snap
1 | XC6220A331MR-G | XC6220A331MR-G | SOT95P280X120-5N | IC4 | LDO Voltage Regulators |  |  |  |  |  |  | https://analytics.supplyframe.com/trackingservlet/track/ | LDO Voltage Regulators |  |  | 1.2mm |  | Torex | XC6220A331MR-G |  |  | 865-XC6220A331MR-G | https://www.mouser.co.uk/ProductDetail/Torex-Semiconductor/XC6220A331MR-G?qs=AsjdqWjXhJ8ZSWznL1J0gg%3D%3D |  |  |  |  |  |  |  |  |  | https://componentsearchengine.com/part-view/XC6220A331MR-G/Torex

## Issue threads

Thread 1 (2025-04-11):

Imbunatatiri si probleme PCB

andreeaudateanu, 2025-04-11:
Am observat cateva aspecte la nivelul PCB-ului, care ar putea fi imbunatatite si modificate.

Closed 2025-04-13.

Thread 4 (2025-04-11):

Modificare unghiuri de 90 de grade

andreeaudateanu, 2025-04-11:
Exista cateva trasee intre componentele de pe PCB care formeaza unghiuri de 90 de grade, acestea nu ar trebui sa existe deoarece pot duce la probleme de buna functionare. Astfel ar fi recomandat sa modifici aceste unghiuri. Poti sterge rutele acestea (selectand optiunea Delete din tab-ul Design->Edit si click pe ruta), apoi selectand optiunea Route Manual le poti desena din nou.

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

Closed 2025-04-13.

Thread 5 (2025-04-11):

Modificare fisier Pick And Place

andreeaudateanu, 2025-04-11:
In fisierul _**Pick And Place.csv**_ din folderul **_Manufacturing_**, prima linie a tabelului este afisata ca fiind si capul de tabel cu denumirile coloanelor, insa pentru a afisa tabelul corespunzator trebuie sa adaugi in fisierul CSV un nou rand la inceputul tabelului care sa contina numele coresponzatoare fiecarei coloane a CSV-ului exportat din Fusion.

Closed 2025-04-13.

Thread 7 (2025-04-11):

Diagrama README

andreeaudateanu, 2025-04-11:
Am observat la diagrama pe care ai atasat-o in README faptul ca unele sageti intre componentele principale nu au un text care sa reprezinte interfata de legatura intre acestea, ai putea adauga asta la diagrama ta pentru a face mai clare legaturile intre componente.

Closed 2025-04-13.

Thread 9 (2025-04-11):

Adaugare Concluzii README

andreeaudateanu, 2025-04-11:
La finalul README-ului ar fi util sa adaugi cateva concluzii legate de realizarea proiectului (ex: erorile care au fost acceptate in implementare si de ce au fost acceptate, cum s-a realizat rutarea componentelor din pcb, reguli de care s-a tinut cont in realizarea design-ului, etc.).

Closed 2025-04-13.

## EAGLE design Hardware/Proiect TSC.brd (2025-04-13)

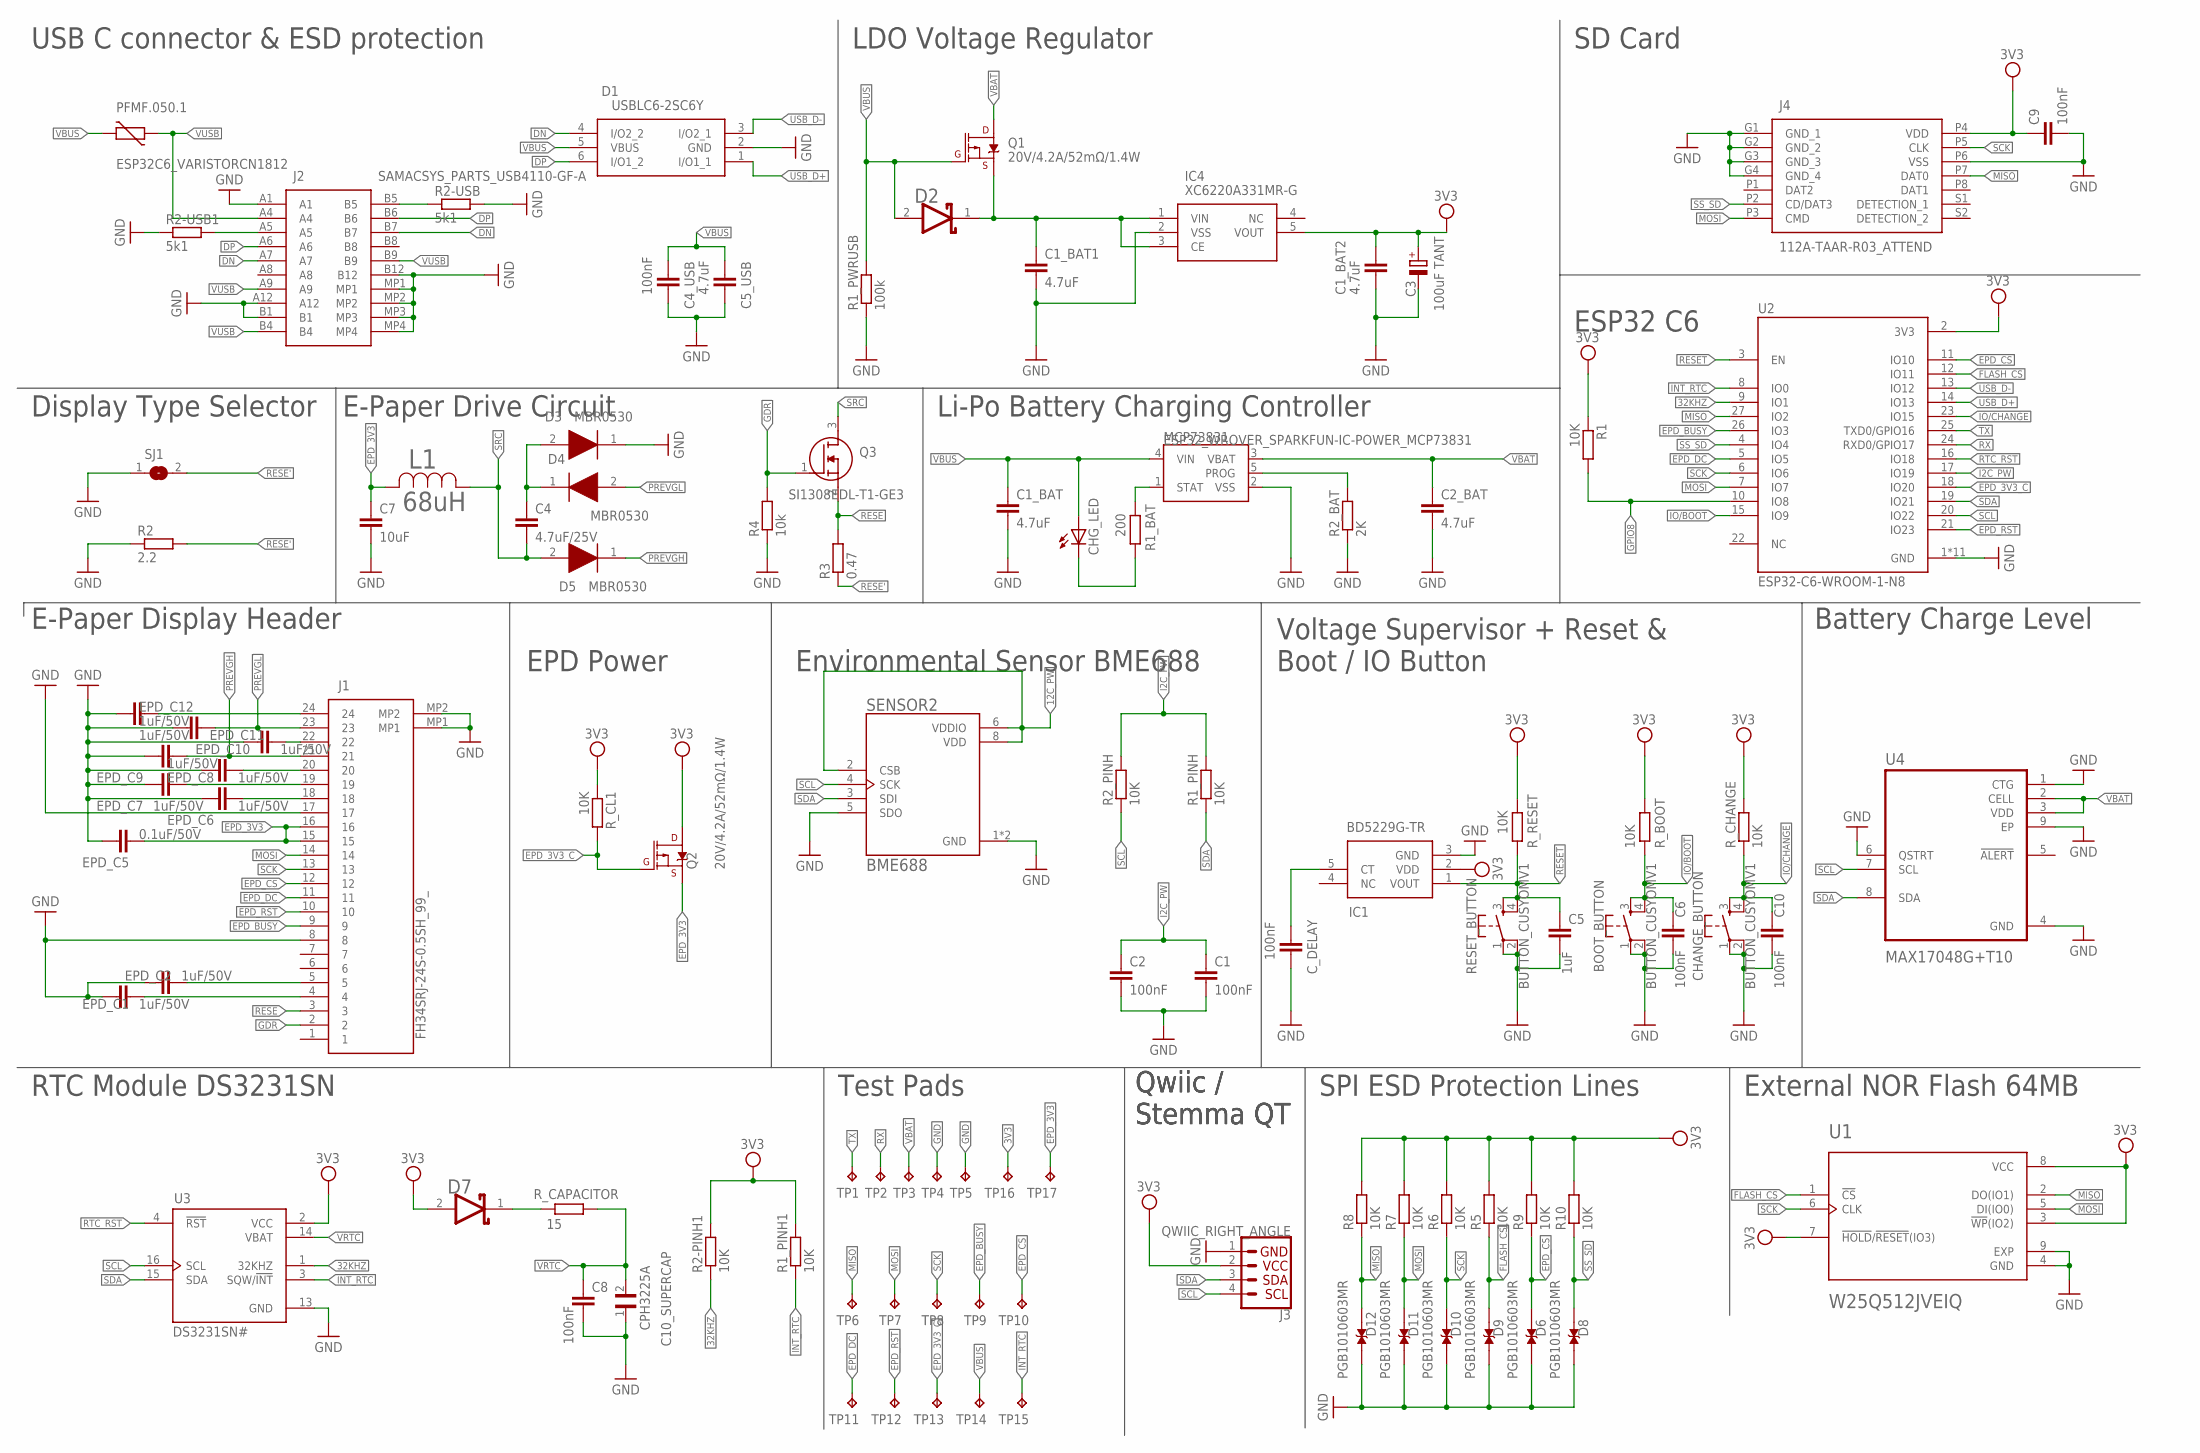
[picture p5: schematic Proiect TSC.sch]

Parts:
BOOT_BUTTON: BUTTON_CUSYOMV1; MYBUTTON
C1, C2, C4_USB, C6, C8, C9, C10: 100nF; EAGLE-LTSPICE_C0402
C1_BAT, C1_BAT1, C1_BAT2, C2_BAT, C5_USB: 4.7uF; EAGLE-LTSPICE_C0402
C3: 100uF TANT; RCL_CT3528
C4: 4.7uF/25V; EAGLE-LTSPICE_C0402
C5: 1uF; EAGLE-LTSPICE_C0402
C7: 10uF; EAGLE-LTSPICE_C0402
C10_SUPERCAP: CPH3225A; CAPCP3225X100N
CHANGE_BUTTON: BUTTON_CUSYOMV1; MYBUTTON
CHG_LED: ADAFRUIT_LEDCHIP-LED0603; ADAFRUIT_CHIP-LED0603
C_DELAY: 100nF; EAGLE-LTSPICE_C0402
D1: USBLC6-2SC6Y; SOT95P280X145-6N
D2: SD0805S020S1R0; ESP32_WROVER_AVX---SD0805S020S1R0_AVX_SD0805S020S1R0_0
D3, D4, D5: MBR0530; SOD3716X135N
D6, D8, D9, D10, D11, D12: PGB1010603MR; DIOC1608X36N
D7: ESP32_WROVER_AVX---SD0805S020S1R0_AVX_SD0805S020S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; ESP32_WROVER_AVX---SD0805S020S1R0_AVX_SD0805S020S1R0_0
EPD_C1, EPD_C2, EPD_C6, EPD_C7, EPD_C8, EPD_C9, EPD_C10, EPD_C11, EPD_C12: 1uF/50V; EAGLE-LTSPICE_C0402
EPD_C5: 0.1uF/50V; EAGLE-LTSPICE_C0402
IC1: BD5229G-TR; SOT95P280X120-5N
IC4: XC6220A331MR-G; SOT95P280X120-5N
J1: FH34SRJ-24S-0.5SH_99_; FH34SRJ24S05SH99
J2: SAMACSYS_PARTS_USB4110-GF-A; SAMACSYS_PARTS_USB4110GFA
J3: QWIIC_RIGHT_ANGLE; JST04_1MM_RA
J4: 112A-TAAR-R03_ATTEND; 112ATAARR03ATTEND
L1: 68uH; IND_4828-WE-TPC_WRE
MCP73831: ESP32_WROVER_SPARKFUN-IC-POWER_MCP73831; ESP32_WROVER_SPARKFUN-IC-POWER_SOT23-5
PFMF.050.1: ESP32C6_VARISTORCN1812; ESP32C6_VARISTOR_CT/CN1812
Q1, Q2: 20V/4.2A/52mΩ/1.4W; ESP32_WROVER_SPARKFUN-DISCRETESEMI_SOT23-3
Q3: SI1308EDL-T1-GE3; SOT65P210X110-3N
R1, R1_PINH, R1_PINH1, R2-PINH1, R2_PINH, R5, R6, R7, R8, R9, R10: 10K; ESP32_WROVER_EAGLE-LTSPICE_R0402
R1_BAT: 200; ESP32_WROVER_EAGLE-LTSPICE_R0402
R1_PWRUSB: 100k; ESP32_WROVER_EAGLE-LTSPICE_R0402
R2: 2.2; ESP32_WROVER_EAGLE-LTSPICE_R0402
R2-USB, R2-USB1: 5k1; ESP32_WROVER_EAGLE-LTSPICE_R0402
R2_BAT: 2K; ESP32_WROVER_EAGLE-LTSPICE_R0402
R3: 0.47; ESP32_WROVER_EAGLE-LTSPICE_R0402
R4: 10k; ESP32_WROVER_EAGLE-LTSPICE_R0402
RESET_BUTTON: BUTTON_CUSYOMV1; MYBUTTON
R_BOOT: 10K; ESP32_WROVER_EAGLE-LTSPICE_R0402
R_CAPACITOR: 15; ESP32_WROVER_EAGLE-LTSPICE_R0402
R_CHANGE: 10K; ESP32_WROVER_EAGLE-LTSPICE_R0402
R_CL1: 10K; ESP32_WROVER_EAGLE-LTSPICE_R0402
R_RESET: 10K; ESP32_WROVER_EAGLE-LTSPICE_R0402
SENSOR2: BME688; ESP32_WROVER_BME680_PSON80P300X300X100-8N
SJ1: SJ
TP1, TP2, TP3, TP4, TP5, TP6, TP7, TP8, TP9, TP10, TP11, TP12, TP13, TP14, TP15, TP16, TP17: TPTP20R; TP20R
U1: W25Q512JVEIQ; SON127P600X800X80-9N
U2: ESP32-C6-WROOM-1-N8; XCVR_ESP32-C6-WROOM-1-N8
U3: DS3231SN#; SOIC127P1032X265-16N
U4: MAX17048G+T10; SON50P200X200X80-9N

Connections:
3V3: C1_BAT2.1, C3.+, C9.1, D7.2 (ANODE), IC1.2 (VDD), IC4.5 (VOUT), J3.2, J4.P4 (VDD), Q2.3 (D), R1.1, R1_PINH1.2, R2-PINH1.2, R5.2, R6.2, R7.2, R8.2, R9.2, R10.2, R_BOOT.2, R_CHANGE.2, R_CL1.1, R_RESET.2, TP16.TP, U1.3 (!WP!(IO2)), U1.7 (!HOLD!/!RESET!(IO3)), U1.8 (VCC), U2.2 (3V3), U3.2 (VCC)
12C_PW: SENSOR2.2 (CSB), SENSOR2.6 (VDDIO), SENSOR2.8 (VDD)
32KHZ: R2-PINH1.1, U2.9 (IO1), U3.1 (32KHZ)
DN: D1.4 (I/O2_2), J2.A7, J2.B7
DP: D1.6 (I/O1_2), J2.A6, J2.B6
EPD_3V3: C7.1, EPD_C5.1, J1.15, J1.16, L1.2, Q2.2 (S), TP17.TP
EPD_3V3_C: Q2.1 (G), R_CL1.2, TP13.TP, U2.18 (IO20)
EPD_BUSY: J1.9, TP9.TP, U2.26 (IO3)
EPD_CS: D6.2, J1.12, R9.1, TP10.TP, U2.11 (IO10)
EPD_DC: J1.11, TP11.TP, U2.5 (IO5)
EPD_RST: J1.10, TP12.TP, U2.21 (IO23)
FLASH_CS: D9.2, R5.1, U1.1 (!CS), U2.12 (IO11)
GDR: J1.2, Q3.1 (G), R4.2
GND: BOOT_BUTTON.1, BOOT_BUTTON.2, C1.2, C1_BAT.2, C1_BAT1.2, C1_BAT2.2, C2.2, C2_BAT.2, C3.-, C4_USB.2, C5.2, C5_USB.2, C6.2, C7.2, C8.2, C9.2, C10.2, C10_SUPERCAP.1, CHANGE_BUTTON.1, CHANGE_BUTTON.2, C_DELAY.2, D1.2 (GND), D3.1 (K), D6.1, D8.1, D9.1, D10.1, D11.1, D12.1, EPD_C1.2, EPD_C2.2, EPD_C5.2, EPD_C6.2, EPD_C7.2, EPD_C8.2, EPD_C9.2, EPD_C10.2, EPD_C11.2, EPD_C12.2, IC1.3 (GND), IC4.2 (VSS), J1.8, J1.17, J1.MP1, J1.MP2, J2.A1, J2.A12, J2.B1, J2.B12, J2.MP1, J2.MP2, J2.MP3, J2.MP4, J3.1, J4.G1 (GND_1), J4.G2 (GND_2), J4.G3 (GND_3), J4.G4 (GND_4), J4.P6 (VSS), MCP73831.2 (VSS), R1_PWRUSB.1, R2.1, R2-USB.2, R2-USB1.1, R2_BAT.1, R4.1, RESET_BUTTON.1, RESET_BUTTON.2, SENSOR2.1 (GND), SENSOR2.5 (SDO), SENSOR2.7 (GND), SJ1.1, TP4.TP, TP5.TP, U1.4 (GND), U1.9 (EXP), U2.1 (GND), U2.28 (GND), U2.29_1 (GND), U2.29_2 (GND), U2.29_3 (GND), U2.29_4 (GND), U2.29_5 (GND), U2.29_6 (GND), U2.29_7 (GND), U2.29_8 (GND), U2.29_9 (GND), U3.13 (GND), U4.1 (CTG), U4.4 (GND), U4.6 (QSTRT), U4.9 (EP)
GPIO8: R1.2, U2.10 (IO8)
I2C_PW: C1.1, C2.1, R1_PINH.2, R2_PINH.2, U2.17 (IO19)
INT_RTC: R1_PINH1.1, TP15.TP, U2.8 (IO0), U3.3 (SQW/!INT)
IO/BOOT: BOOT_BUTTON.3, BOOT_BUTTON.4, C6.1, R_BOOT.1, U2.15 (IO9)
IO/CHANGE: C10.1, CHANGE_BUTTON.3, CHANGE_BUTTON.4, R_CHANGE.1, U2.23 (IO15)
MISO: D12.2, J4.P7 (DAT0), R8.1, TP6.TP, U1.2 (DO(IO1)), U2.27 (IO2)
MOSI: D11.2, J1.14, J4.P3 (CMD), R7.1, TP7.TP, U1.5 (DI(IO0)), U2.7 (IO7)
unnamed: CHG_LED.C, R1_BAT.1
unnamed: J2.A5, R2-USB1.2
unnamed: EPD_C12.1, J1.24
unnamed: C1_BAT1.1, D2.1 (CATHODE), IC4.1 (VIN), IC4.3 (CE), Q1.2 (S)
unnamed: C4.1, D3.2 (A), D4.1 (K)
unnamed: MCP73831.1 (STAT), R1_BAT.2
unnamed: MCP73831.5 (PROG), R2_BAT.2
unnamed: C_DELAY.1, IC1.5 (CT)
unnamed: EPD_C10.1, J1.22
unnamed: J2.B5, R2-USB.1
unnamed: D7.1 (CATHODE), R_CAPACITOR.2
unnamed: EPD_C8.1, J1.20
unnamed: EPD_C7.1, J1.19
unnamed: EPD_C6.1, J1.18
unnamed: EPD_C2.1, J1.5
unnamed: EPD_C1.1, J1.4
PREVGH: D5.1 (K), EPD_C9.1, J1.21
PREVGL: D4.2 (A), EPD_C11.1, J1.23
RESE: J1.3, Q3.2 (S), R3.2
RESE': R2.2, R3.1, SJ1.2
RESET: C5.1, IC1.1 (VOUT), RESET_BUTTON.3, RESET_BUTTON.4, R_RESET.1, U2.3 (EN)
RTC_RST: U2.16 (IO18), U3.4 (!RST)
RX: TP2.TP, U2.24 (RXD0/GPIO17)
SCK: D10.2, J1.13, J4.P5 (CLK), R6.1, TP8.TP, U1.6 (CLK), U2.6 (IO6)
SCL: J3.4, R2_PINH.1, SENSOR2.4 (SCK), U2.20 (IO22), U3.16 (SCL), U4.7 (SCL)
SDA: J3.3, R1_PINH.1, SENSOR2.3 (SDI), U2.19 (IO21), U3.15 (SDA), U4.8 (SDA)
SRC: C4.2, D5.2 (A), L1.1, Q3.3 (D)
SS_SD: D8.2, J4.P2 (CD/DAT3), R10.1, U2.4 (IO4)
TX: TP1.TP, U2.25 (TXD0/GPIO16)
USB_D+: D1.1 (I/O1_1), U2.14 (IO13)
USB_D-: D1.3 (I/O2_1), U2.13 (IO12)
VBAT: C2_BAT.1, MCP73831.3 (VBAT), Q1.3 (D), TP3.TP, U4.2 (CELL), U4.3 (VDD)
VBUS: C1_BAT.1, C4_USB.1, C5_USB.1, CHG_LED.A, D1.5 (VBUS), D2.2 (ANODE), MCP73831.4 (VIN), PFMF.050.1.2, Q1.1 (G), R1_PWRUSB.2, TP14.TP
VRTC: C8.1, C10_SUPERCAP.2, R_CAPACITOR.1, U3.14 (VBAT)
VUSB: J2.A4, J2.A9, J2.B4, J2.B9, PFMF.050.1.1

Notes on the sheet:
USB C connector & ESD protection
LDO Voltage Regulator
SD Card
Display Type Selector
E-Paper Drive Circuit
Li-Po Battery Charging Controller
ESP32 C6
E-Paper Display Header
EPD Power
Environmental Sensor BME688
Voltage Supervisor + Reset & Boot / IO Button
Battery Charge Level
RTC Module DS3231SN
Test Pads
Qwiic / Stemma QT
SPI ESD Protection Lines
External NOR Flash 64MB

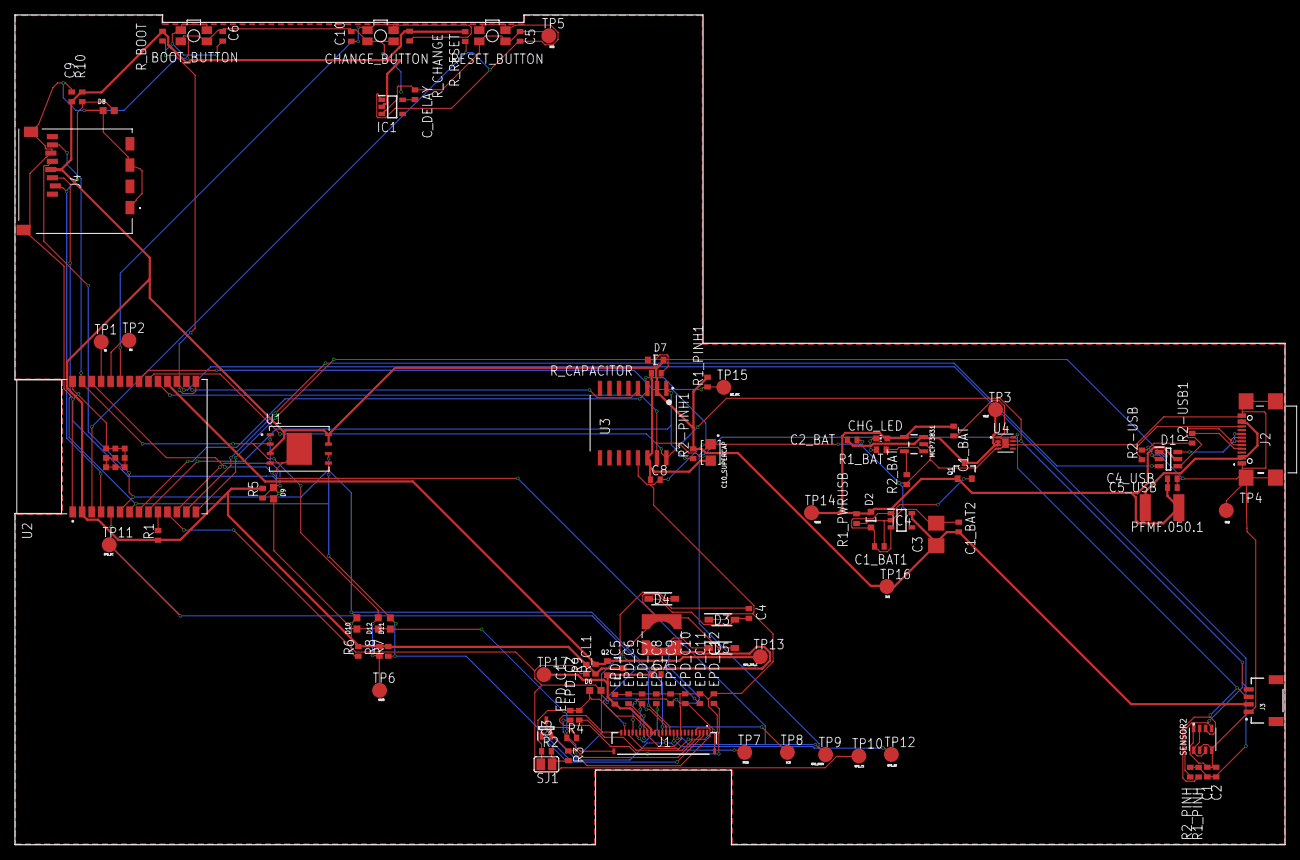
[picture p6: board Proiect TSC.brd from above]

Board: 2 copper layers, 170.2 x 111.2 mm, 103 parts (0 on the bottom side), 56 nets.

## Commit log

2025-04-06 First commit to be safe than sorry :P
    [BOM.csv, PnP_Proiect TSC v34_front.csv, Proiect TSC v29.sch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]
2025-04-06 Hopefully, first full version...
    [Pick and Place.csv, Proiect TSC.brd, Proiect TSC.sch]
2025-04-13 Fixes #1 #2 #3 #4 #5 #6 #7 #8 #9
    [BOM.csv, Pick and Place.csv, Proiect TSC.brd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]

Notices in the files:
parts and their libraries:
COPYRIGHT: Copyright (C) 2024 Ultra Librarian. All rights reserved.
